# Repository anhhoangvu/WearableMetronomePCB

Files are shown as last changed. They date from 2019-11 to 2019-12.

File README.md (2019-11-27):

WEARABLE METRONOME by HOANG VU

PCB Repository for the project.

Project for PocketBeagle which uses Python to create an interface for an arm-mounted metronome using vibrational motors to create rhythms and interacting with surrounding sound. Please visit https://www.hackster.io/hoangvu/wearable-metronome-53c2b7 for a complete tutorial and build instructions.

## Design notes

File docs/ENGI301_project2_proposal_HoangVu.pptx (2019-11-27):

## ENGI 301 Wearable Metronome Proposal – Project 2

11/26/2019
Hoang Vu

## Background Information

- A wearable metronome/sound sensor, functions include:
  - Vibrates at a set tempo
  - LED patterns according to noise level
  - Optional (different mode for different rhythms/scales)
- Advantage: replace traditional sound metronome with vibrational indication direct to musicians
  - Do not interfere with recording
  - Usable in loud noise situation

## Board Functionality

- PCB consists of a wearable metronome that vibrates at a set tempo and reacts to surrounding music
- Components includes
  - PocketBeagle as a central processing unit
  - HEX display to display the tempo
  - Button to control the tempo
  - Vibrational motors
  - USB connection to power source
  - USB connection to microphone

## System Block Diagram

Multifunctional Button

330 Ohms Resistor

GPIO117

3.3V

GND

PocketBeagle

4-digit 7-segment Display

PWM0BPWM1A
PWM2B

GPIO58

LED + 680 Ohms resistor

Vibrational Motor

Power Bank

Microphone
(through microusb breakout board and audio adapter

USB Port

USB1

I2C2

## Power Block Diagram

GPIO117

Multifunctional Button

330 Ohms Resistor

GND

PocketBeagle

4-digit 7-segment Display

PWM0BPWM1A
PWM2B

GPIO58

LED + 680 Ohms resistor

Vibrational Motor

Power Bank

Microphone
(through microusb breakout board and audio adapter

USB Port

USB1

I2C2

3.3V

3.3V

5V

85 mA

3.3V

## Mechanical Block Diagram

HEK Display
2’’ x 0.75’’

3’’ x 2.5’’ PCB - Front

PocketBeagle
2’’ x 1.25’’

3’’ x 2.5’’ PCB - Back

LED Connection

Button

USB2 Connection

Vibrating motors

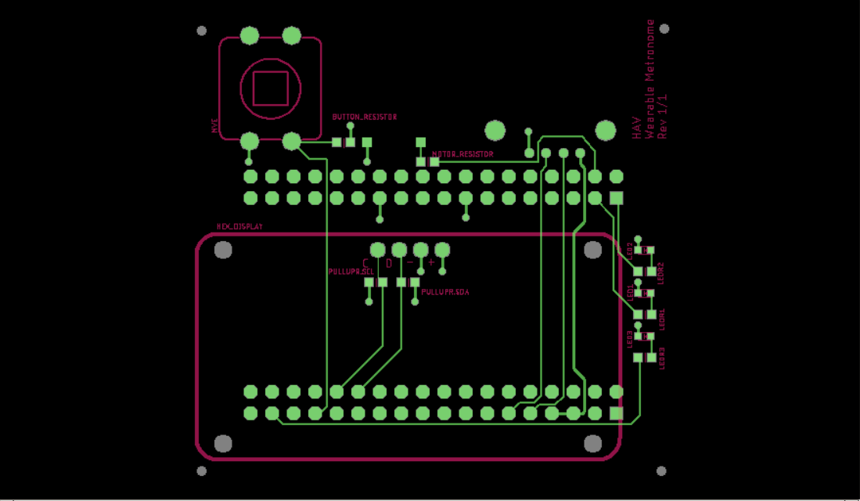
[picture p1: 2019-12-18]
docs/PCB_Top_Gerb.PNG

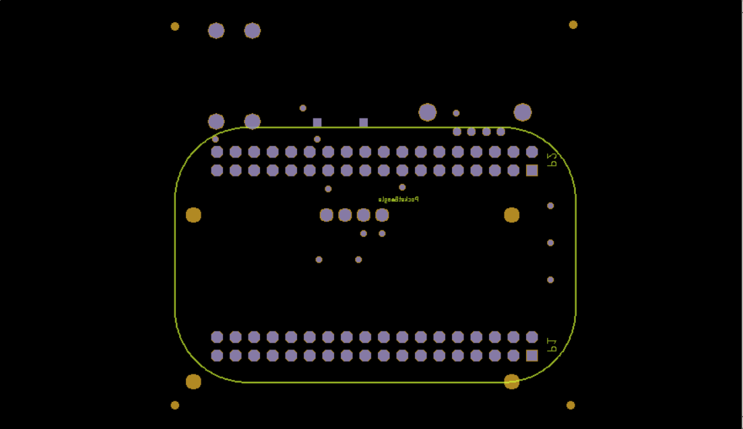
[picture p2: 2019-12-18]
docs/PCB_Bottom_Gerb.PNG

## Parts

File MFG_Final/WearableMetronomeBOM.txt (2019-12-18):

Partlist exported from C:/Users/Hooooaaanng/Documents/EAGLE/projects/Wearable Netronome/WearableMetronome.sch at 12/18/2019 4:03 PM

Qty Value              Device             Package            Parts                               Description                                 
1   0.56_HEX_BACKPACK  0.56_HEX_BACKPACK  0.56_HEX_BACKPACK  HEX_DISPLAY                         0.56" LED HEX Backback - Adafruit HT16K33 - 
2   10k                R_R0603            R0603              PULLUPR.SCL, PULLUPR.SDA            RESISTOR, American symbol                   
1   1k                 R_R0603            R0603              BUTTON_RESISTOR                     RESISTOR, American symbol                   
4   330                R_R0603            R0603              LEDR1, LEDR2, LEDR3, MOTOR_RESISTOR RESISTOR, American symbol                   
3   LED                LED                EIA-STD            LED1, LED2, LED3                    LTST-C191TBKT Series of LEDs                
1   POCKETBEAGLE_HOANG POCKETBEAGLE_HOANG POCKETBEAGLE_HOANG U$3                                                                             
1   PUSH_BUTTON        PUSH_BUTTON        BUTTON_12.5MM      MVE                                                                             
1   USBAFEMALE         USBAFEMALE         USBAFEMALE         U$1                                                                             
1   VIBRATIONALMOTOR   VIBRATIONALMOTOR   VIBRATIONALMOTOR   U$2

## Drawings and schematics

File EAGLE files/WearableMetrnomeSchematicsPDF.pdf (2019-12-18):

A

A

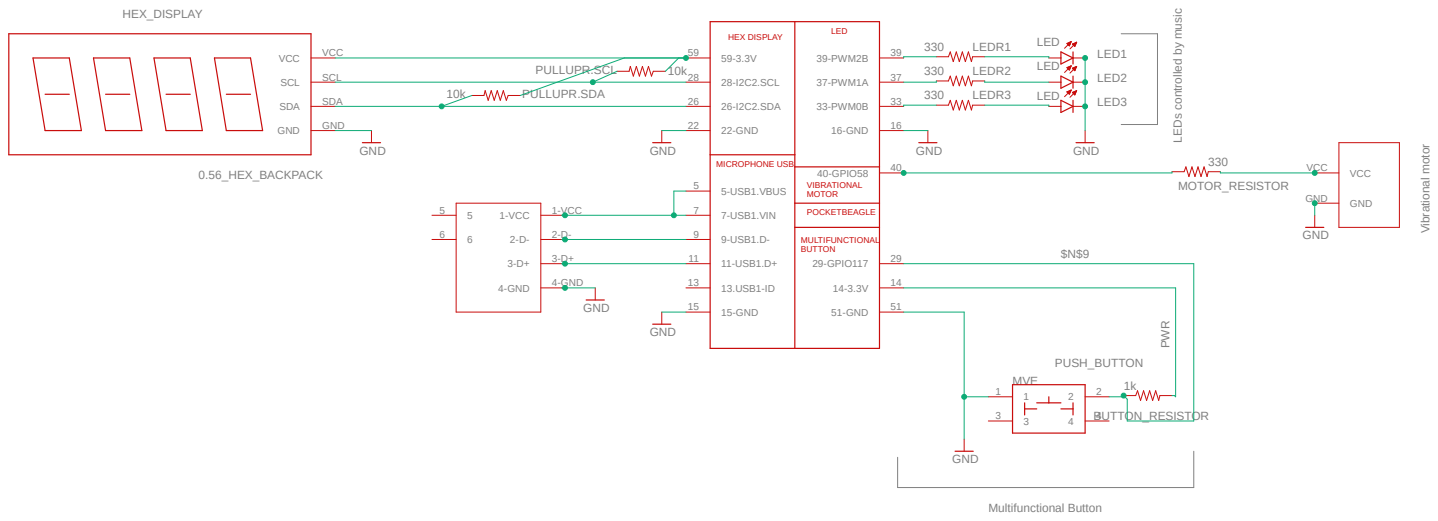
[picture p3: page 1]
0.56_HEX_BACKPACK; MVE; PUSH_BUTTON; LED; GND; LEDs controlled by music; Vibrational motor; Multifunctional Button; SCL; SCL SDA; SDA; VCC; HEX_DISPLAY; LED3; MOTOR_RESISTOR; LED2; LED1; LEDR2; LEDR1; LEDR3; BUTTON_RESISTOR; PULLUPR.SDA; PULLUPR.SCL; 5-USB1.VBUS 5; 7-USB1.VIN 7; 9-USB1.D- 9; 11-USB1.D+ 11; 13.USB1-ID 13; 15-GND 15; 26-I2C2.SDA 26; 28-I2C2.SCL 28; 29-GPIO117; 33-PWM0B; 37-PWM1A; 39-PWM2B; 40-GPIO58; 51-GND; 1-VCC; 4-GND; 6 GND GND; Wearable Metronome; Sheet:; Rev 1 1/1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

HEX DISPLAY 59-3.3V 59 | LED MULTIFUNCTIONAL BUTTON 16-GND | 16 22-GND 22

POCKETBEAGLE MICROPHONE USB

VCC VCC PWR

Hoang-Anh Vu

12/18/2019 1:32 PM C:\Users\Hooooaaanng\Documents\EAGLE\projects\Wearable Netronome\WearableMetronome.sch (Sheet: 1/1)

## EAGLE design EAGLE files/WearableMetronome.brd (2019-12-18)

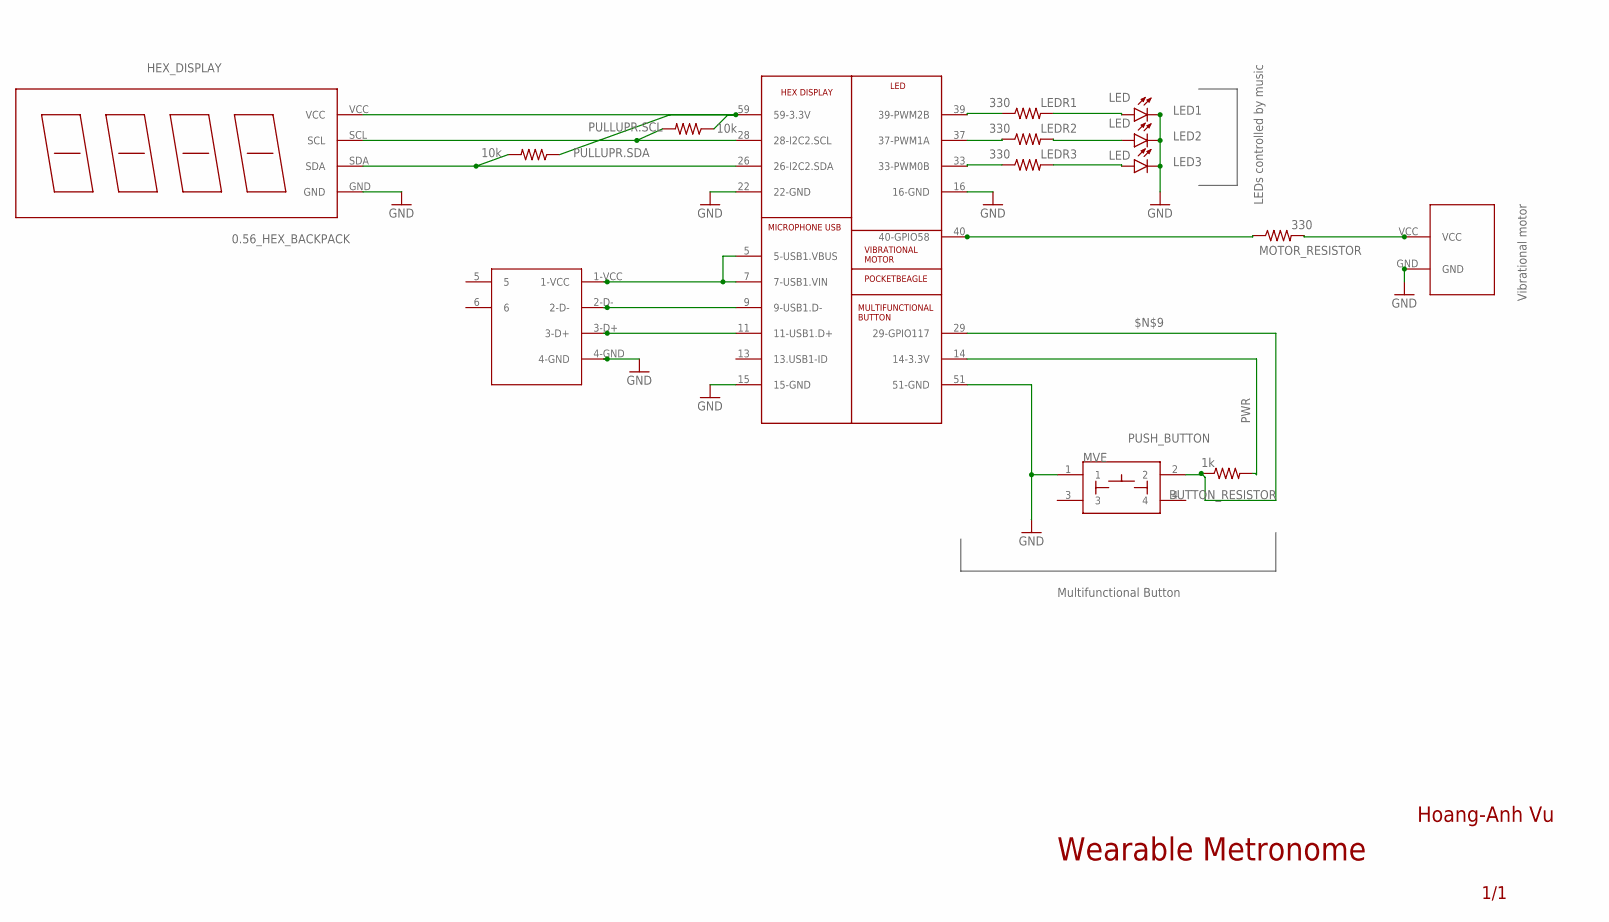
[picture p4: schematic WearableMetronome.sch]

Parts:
BUTTON_RESISTOR: 1k; R0603
HEX_DISPLAY: 0.56_HEX_BACKPACK
LED1, LED2, LED3: LED; EIA-STD
LEDR1, LEDR2, LEDR3: 330; R0603
MOTOR_RESISTOR: 330; R0603
MVE: PUSH_BUTTON; BUTTON_12.5MM
PULLUPR.SCL, PULLUPR.SDA: 10k; R0603
U$1: USBAFEMALE
U$2: VIBRATIONALMOTOR
U$3: POCKETBEAGLE_HOANG

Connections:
$N$9: BUTTON_RESISTOR.1, MVE.2, U$3.29 (29-GPIO117)
GND: HEX_DISPLAY.GND, LED1.P$2 (C), LED2.P$2 (C), LED3.P$2 (C), MVE.1, U$1.4-GND, U$2.GND, U$3.15 (15-GND), U$3.16 (16-GND), U$3.22 (22-GND), U$3.51 (51-GND)
unnamed: HEX_DISPLAY.SCL, PULLUPR.SCL.2, U$3.28 (28-I2C2.SCL)
unnamed: HEX_DISPLAY.SDA, PULLUPR.SDA.2, U$3.26 (26-I2C2.SDA)
unnamed: MOTOR_RESISTOR.2, U$2.VCC
unnamed: U$1.1-VCC, U$3.5 (5-USB1.VBUS), U$3.7 (7-USB1.VIN)
unnamed: U$1.2-D-, U$3.9 (9-USB1.D-)
unnamed: U$1.3-D+, U$3.11 (11-USB1.D+)
unnamed: MOTOR_RESISTOR.1, U$3.40 (40-GPIO58)
unnamed: LEDR3.1, U$3.33 (33-PWM0B)
unnamed: LEDR1.1, U$3.39 (39-PWM2B)
unnamed: LED1.P$1 (A), LEDR1.2
unnamed: LEDR2.1, U$3.37 (37-PWM1A)
unnamed: LED2.P$1 (A), LEDR2.2
unnamed: LED3.P$1 (A), LEDR3.2
PWR: BUTTON_RESISTOR.2, HEX_DISPLAY.VCC, PULLUPR.SCL.1, PULLUPR.SDA.1, U$3.14 (14-3.3V), U$3.59 (59-3.3V)

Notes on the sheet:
LEDs controlled by music
Vibrational motor
Multifunctional Button
Wearable Metronome
Hoang-Anh Vu
1/1

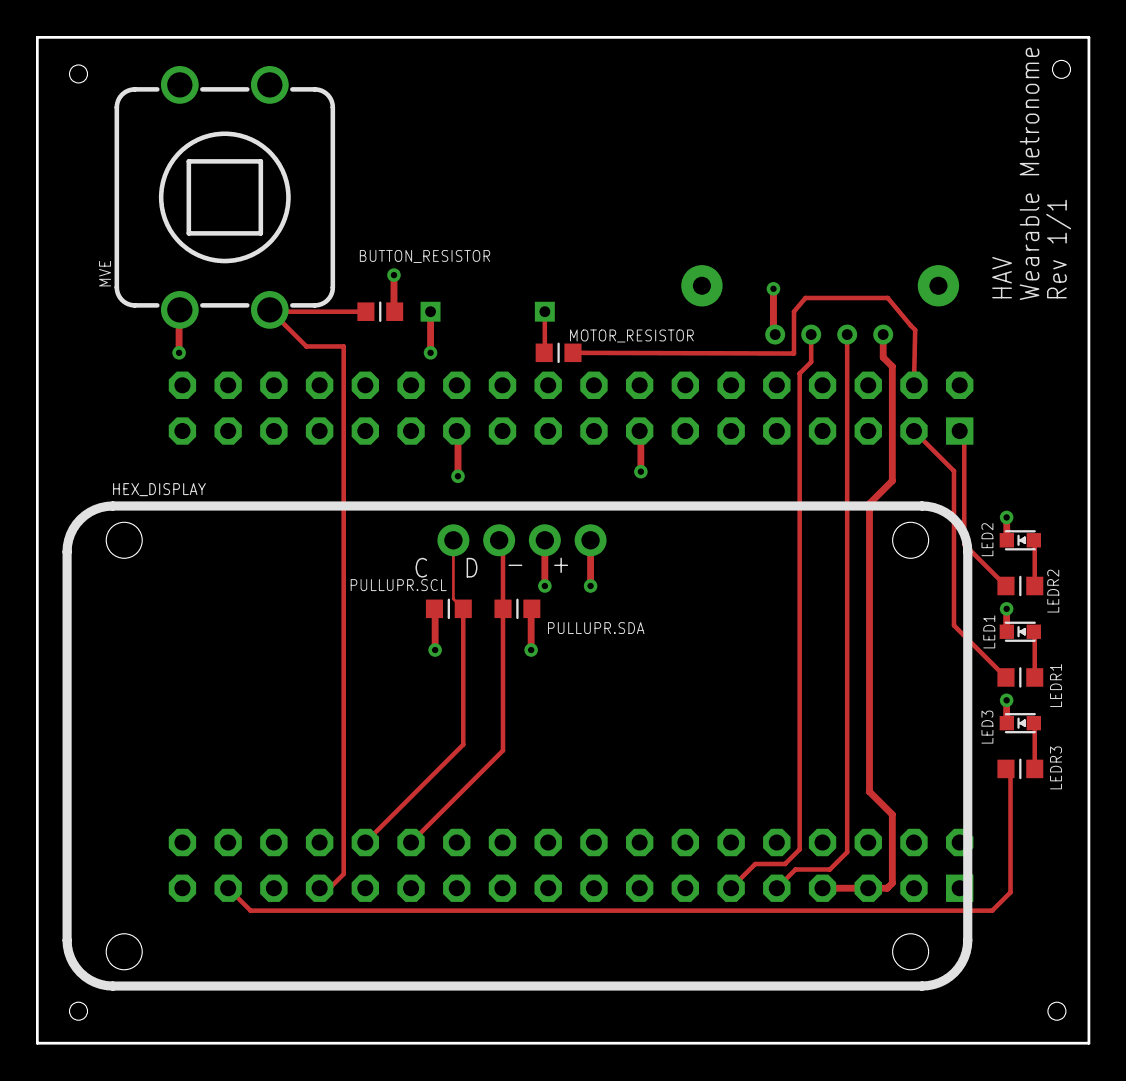
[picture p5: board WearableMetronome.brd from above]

Board: 2 copper layers, 58.4 x 55.9 mm, 15 parts (1 on the bottom side), 16 nets.

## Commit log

2019-12-18 Rename EAGLE files/MFG/copper_bottom_l4.gbr to MFG/copper_bottom_l4.gbr
    [copper_bottom_l4.gbr]
2019-12-18 Rename EAGLE files/MFG/copper_inner_l2.gbr to MFG/copper_inner_l2.gbr
    [copper_inner_l2.gbr]
2019-12-18 Rename EAGLE files/MFG/copper_inner_l3.gbr to MFG/copper_inner_l3.gbr
    [copper_inner_l3.gbr]
2019-12-18 Rename EAGLE files/MFG/copper_top_l1.gbr to MFG/copper_top_l1.gbr
    [copper_top_l1.gbr]
2019-12-18 Rename EAGLE files/MFG/drills.xln to MFG/drills.xln
    [drills.xln]
2019-12-18 Rename EAGLE files/MFG/gerber_job.gbrjob to MFG/gerber_job.gbrjob
    [gerber_job.gbrjob]
2019-12-18 Rename EAGLE files/MFG/profile.gbr to MGF/profile.gbr
    [profile.gbr]
2019-12-18 Rename EAGLE files/MFG/silkscreen_bottom.gbr to MFG/silkscreen_bottom.gbr
    [silkscreen_bottom.gbr]
2019-12-18 Rename EAGLE files/MFG/silkscreen_top.gbr to MFG/silkscreen_top.gbr
    [silkscreen_top.gbr]
2019-12-18 Rename EAGLE files/MFG/soldermask_bottom.gbr to MFG/soldermask_bottom.gbr
    [soldermask_bottom.gbr]
2019-12-18 Rename EAGLE files/MFG/soldermask_top.gbr to MFG/soldermask_top.gbr
    [soldermask_top.gbr]
2019-12-18 Rename EAGLE files/MFG/solderpaste_bottom.gbr to MFG/solderpaste_bottom.gbr
    [solderpaste_bottom.gbr]
2019-12-18 Rename EAGLE files/MFG/solderpaste_top.gbr to MFG/solderpaste_top.gbr
    [solderpaste_top.gbr]
